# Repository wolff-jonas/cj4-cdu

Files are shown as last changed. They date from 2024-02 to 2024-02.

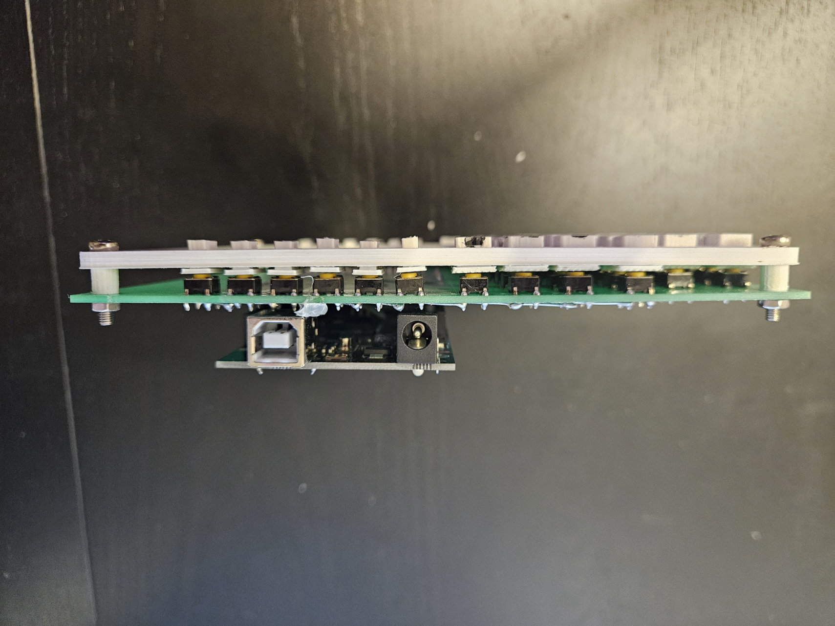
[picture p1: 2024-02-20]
images/side.jpg

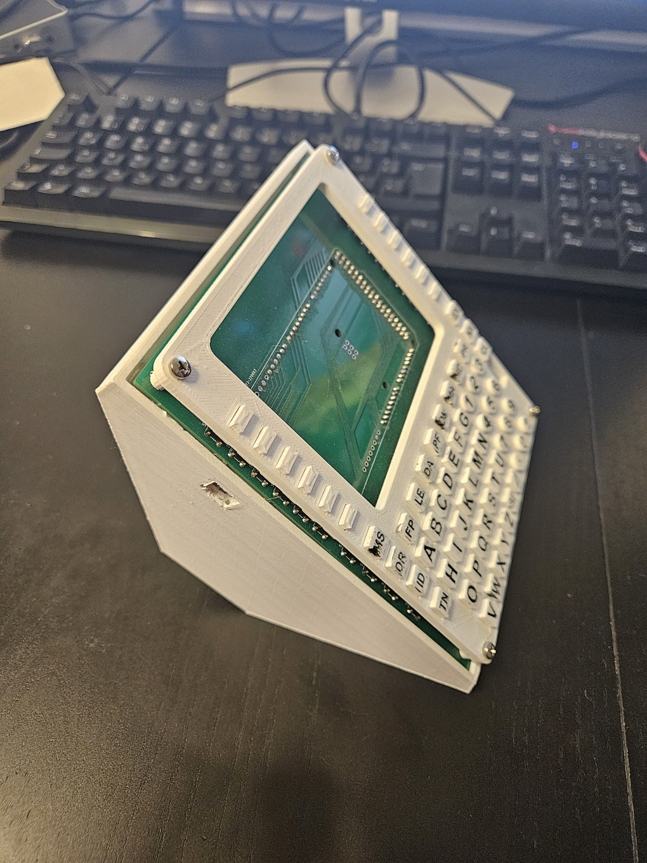
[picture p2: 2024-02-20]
images/side_stand.jpg

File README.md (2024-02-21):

# Overview

This is a physical button box in the rough shape and functionality of the CDU of the Citation CJ4.
It is primarily intended for use with Microsoft Flight Simulator 2020, but could be adapted to other simulators (or planes) as well.

For more indepth information head over to: https://jwolff.it/cj4-cdu/

## Hardware 

It's constructed with a 3D printed front plate, 3D printed keys, a custom PCB and an Arduino Mega.

The CAD for the front plate, and the 3 different kinds of keys are in CAD/ folder.
The is only one key for each type. For the whole keyboard you would have to copy and modify them with the labeling.

The schematics and design files for the PCB are in the kicad/ folder.

> [!CAUTION]
> If you plan on using the PCB: __triple check the footprints__ of the buttons!
>
> The buttons I ordered had different footprints. I had manually rework all the ground wires to make it work.
> I did __not__ update the PCB.

## Software

This uses [Mobiflight](https://www.mobiflight.com) for sending the correct key events to the sim.
Make sure you have the WASM module installed and downloaded the CJ4 Preset from HubHop.

The configs file mobiflight are in the mobiflight/ folder.

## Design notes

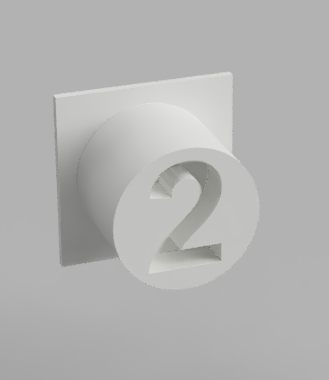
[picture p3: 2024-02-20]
images/button_round.png

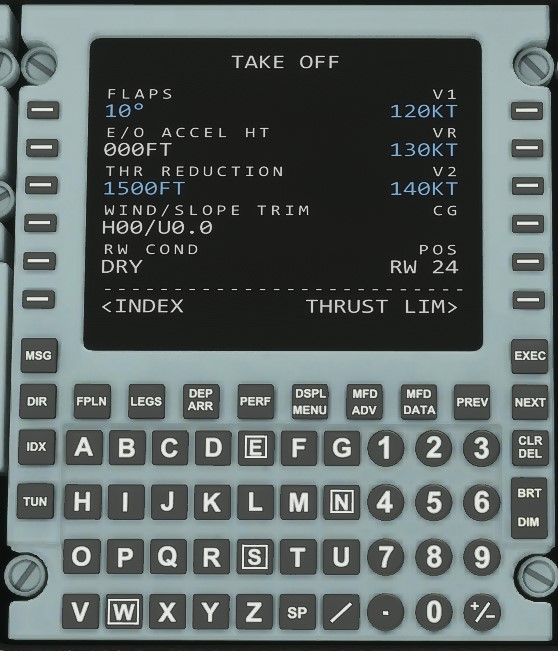
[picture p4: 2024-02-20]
images/screenshot.jpeg

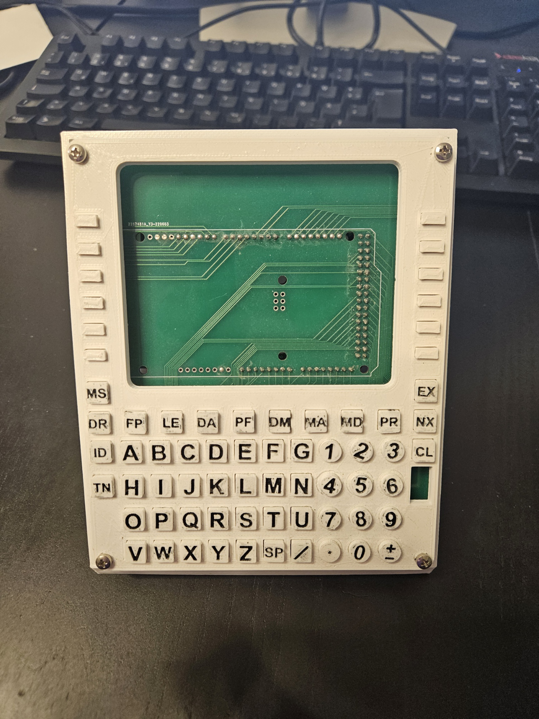
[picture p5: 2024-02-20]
images/front.jpg

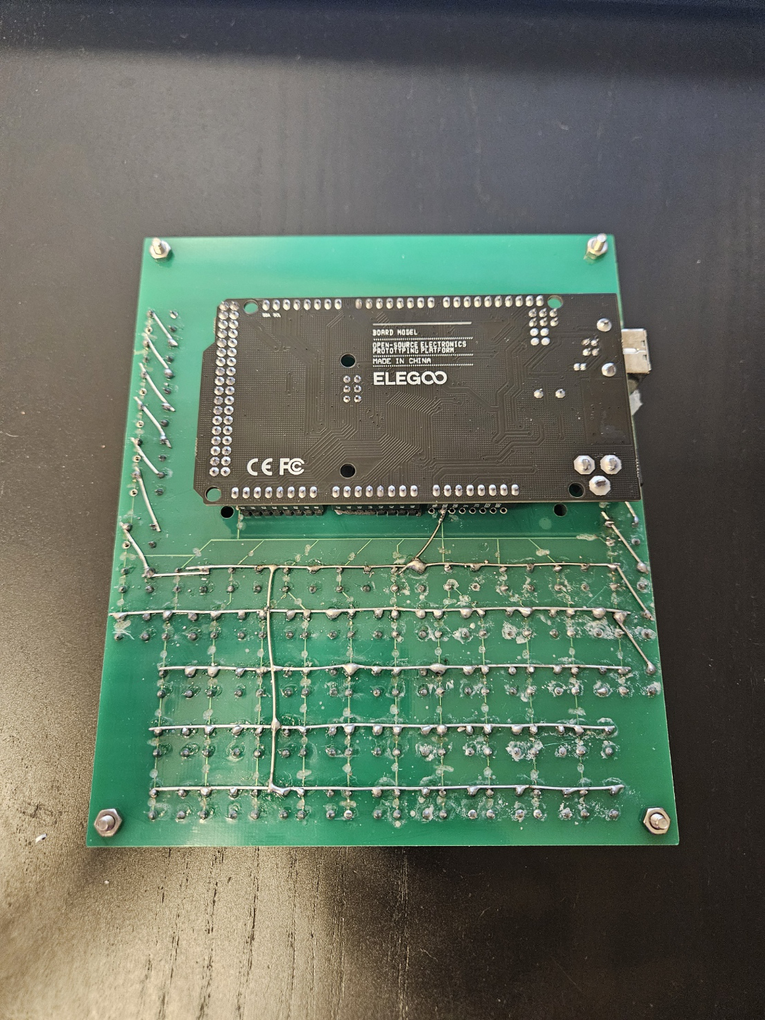
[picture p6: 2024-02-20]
images/back.jpg

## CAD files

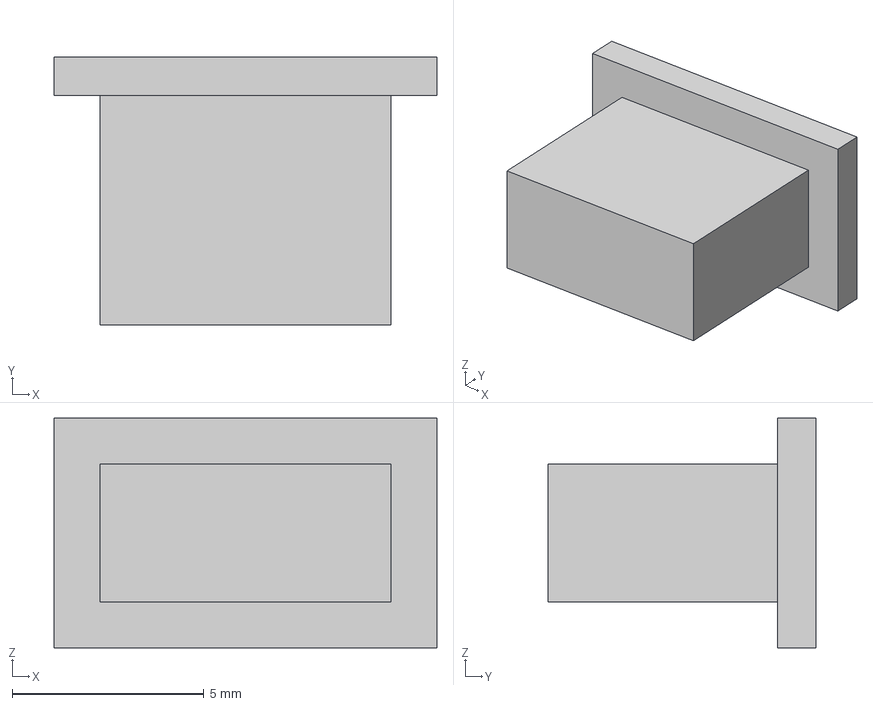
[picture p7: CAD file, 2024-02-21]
cad/key_lsk.step
10.0 x 7.00 x 6.00 mm

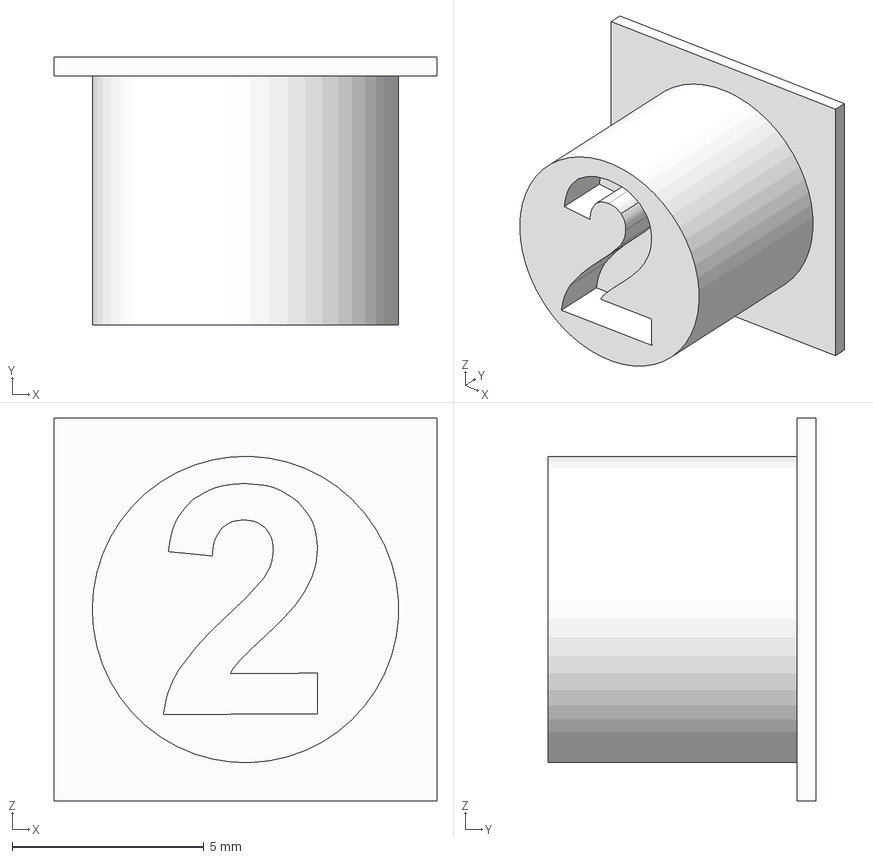
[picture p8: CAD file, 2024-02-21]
cad/key_round.step
10.0 x 7.00 x 10.0 mm

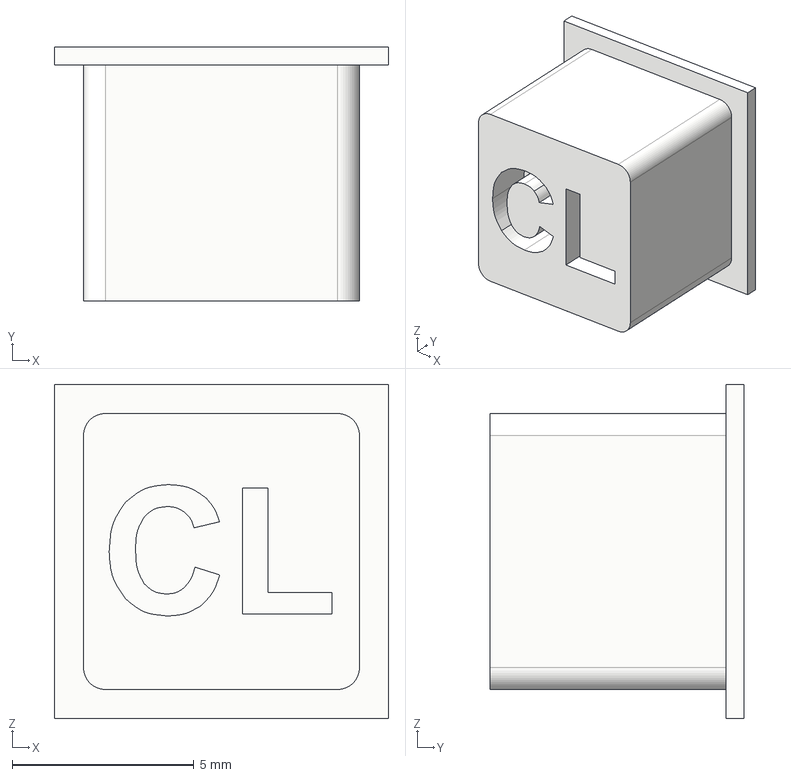
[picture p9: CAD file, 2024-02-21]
cad/key_square.step
9.20 x 7.00 x 9.20 mm

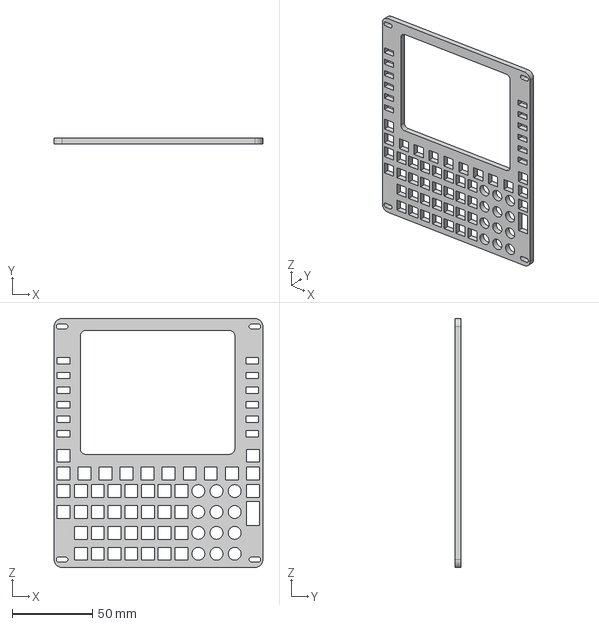
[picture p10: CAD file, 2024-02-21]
cad/frontpanel.step
130.0 x 4.00 x 155.0 mm

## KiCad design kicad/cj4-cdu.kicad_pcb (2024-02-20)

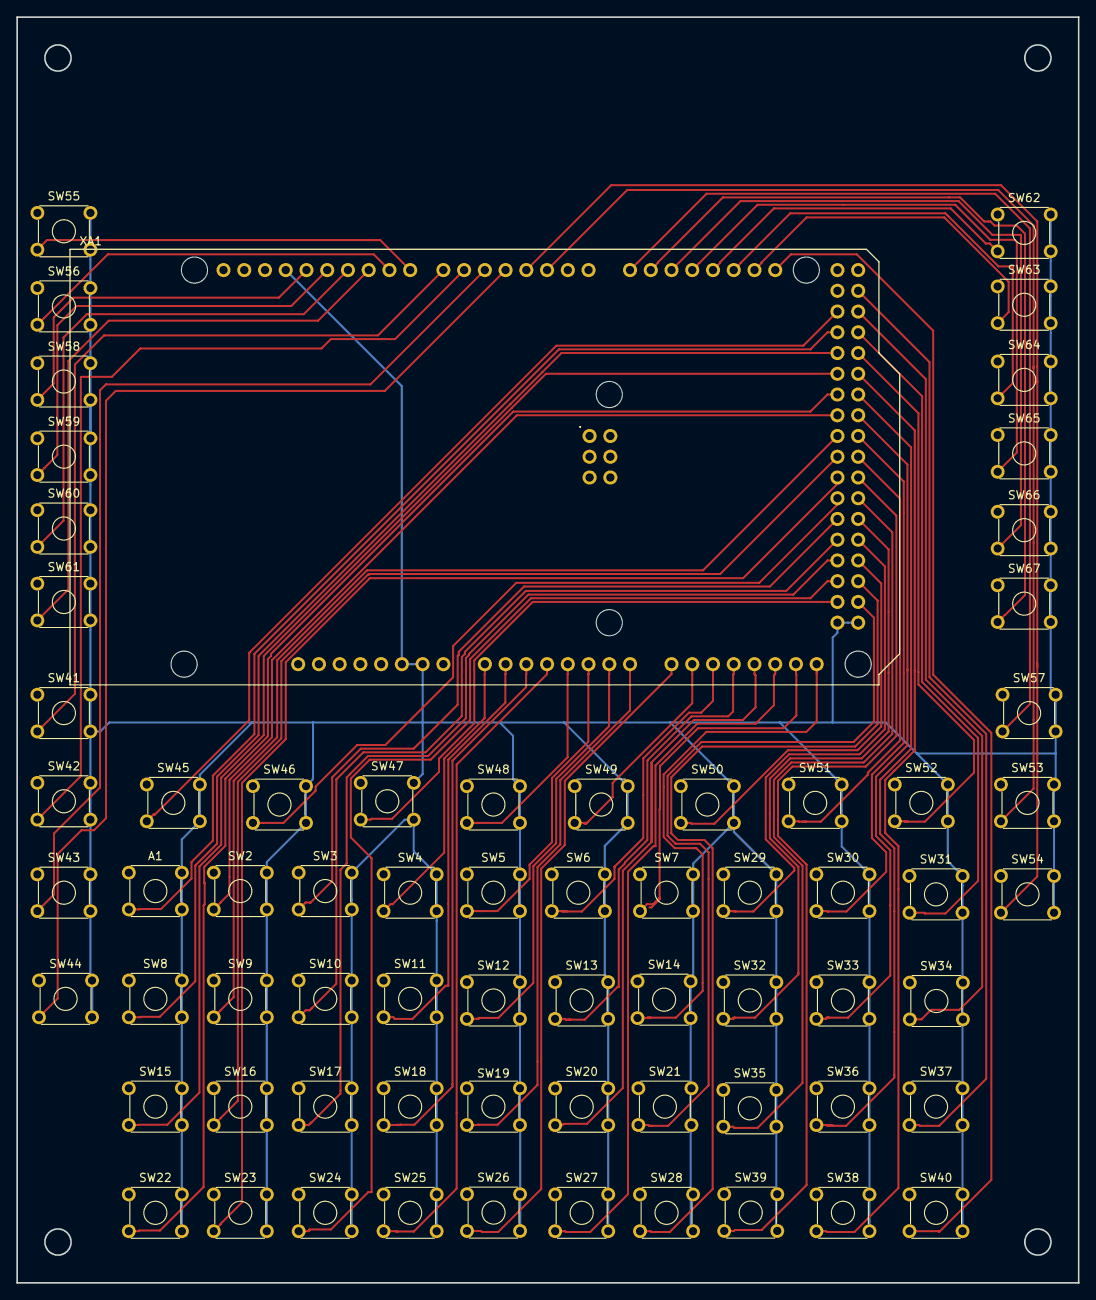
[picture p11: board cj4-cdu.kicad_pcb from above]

Board: 2 copper layers, 130.0 x 155.0 mm, 68 parts (0 on the bottom side), 68 nets.

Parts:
A1: A; SW_TH_Tactile_Omron_B3F-10xx
SW2: B; SW_TH_Tactile_Omron_B3F-10xx
SW3: C; SW_TH_Tactile_Omron_B3F-10xx
SW4: D; SW_TH_Tactile_Omron_B3F-10xx
SW5: E; SW_TH_Tactile_Omron_B3F-10xx
SW6: F; SW_TH_Tactile_Omron_B3F-10xx
SW7: G; SW_TH_Tactile_Omron_B3F-10xx
SW8: H; SW_TH_Tactile_Omron_B3F-10xx
SW9: I; SW_TH_Tactile_Omron_B3F-10xx
SW10: J; SW_TH_Tactile_Omron_B3F-10xx
SW11: K; SW_TH_Tactile_Omron_B3F-10xx
SW12: L; SW_TH_Tactile_Omron_B3F-10xx
SW13: M; SW_TH_Tactile_Omron_B3F-10xx
SW14: N; SW_TH_Tactile_Omron_B3F-10xx
SW15: Q; SW_TH_Tactile_Omron_B3F-10xx
SW16: P; SW_TH_Tactile_Omron_B3F-10xx
SW17, SW18, SW19, SW20, SW21, SW22, SW23, SW24, SW25, SW26, SW27, SW28, SW29, SW30, SW31, SW32, SW33, SW34, SW35, SW36, SW37, SW38, SW39, SW40, SW41, SW42, SW43, SW44, SW45, SW46, SW47, SW48, SW49, SW50, SW51, SW52, SW53, SW54, SW55, SW56, SW57, SW58, SW59, SW60, SW61, SW62, SW63, SW64, SW65, SW66, SW67: SW_DPST; SW_TH_Tactile_Omron_B3F-10xx
XA1: Arduino_Mega2560_Shield

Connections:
/0: SW38.3, XA1.D31
/1: SW29.3, XA1.D47
/2: SW30.3, XA1.D37
/3: SW31.3, XA1.D27
/4: SW32.3, XA1.D45
/5: SW33.3, XA1.D35
/6: SW34.3, XA1.D25
/7: SW35.3, XA1.D43
/8: SW36.3, XA1.D33
/9: SW37.3, XA1.D23
/A: A1.3, XA1.D26
/B: SW2.3, XA1.D34
/C: SW3.3, XA1.D44
/CLRDEL: SW54.3, XA1.D3
/D: SW4.3, XA1.A0
/DEPARR: SW47.3, XA1.D52
/DIR: SW42.3, XA1.D6
/DOT: SW39.3, XA1.D41
/DSPLMENU: SW49.3, XA1.A9
/E: SW5.3, XA1.A5
/EXEC: SW57.3, XA1.D14
/F: SW6.3, XA1.A10
/FPLN: SW45.3, XA1.D24
/G: SW7.3, XA1.A14
/H: SW8.3, XA1.D28
/I: SW9.3, XA1.D36
/IDX: SW43.3, XA1.D5
/J: SW10.3, XA1.D46
/K: SW11.3, XA1.A1
/L: SW12.3, XA1.A6
/LEGS: SW46.3, XA1.D42
/LSK_L1: SW55.3, XA1.D8
/LSK_L2: SW56.3, XA1.D9
/LSK_L3: SW58.3, XA1.D13
/LSK_L4: SW59.3, XA1.D12
/LSK_L5: SW60.3, XA1.D11
/LSK_L6: SW61.3, XA1.D10
/LSK_R1: SW62.3, XA1.D18
/LSK_R2: SW63.3, XA1.D20
/LSK_R3: SW64.3, XA1.D19
/LSK_R4: SW65.3, XA1.D17
/LSK_R5: SW66.3, XA1.D16
/LSK_R6: SW67.3, XA1.D15
/M: SW13.3, XA1.A11
/MFDADV: SW50.3, XA1.D49
/MFDDATA: SW51.3, XA1.D39
/MSG: SW41.3, XA1.D7
/N: SW14.3, XA1.A15
/NEXT: SW53.3, XA1.D2
/O: SW15.3, XA1.D30
/P: SW16.3, XA1.D38
/PERF: SW48.3, XA1.A4
/PLUSMINUS: SW40.3, XA1.D21
/PREV: SW52.3, XA1.D29
/Q: SW17.3, XA1.D48
/R: SW18.3, XA1.A2
/S: SW19.3, XA1.A7
/SLASH: SW28.3, XA1.D51
/SP: SW27.3, XA1.A13
/T: SW20.3, XA1.A12
/TUN: SW44.3, XA1.D4
/U: SW21.3, XA1.D53
/V: SW22.3, XA1.D32
/W: SW23.3, XA1.D40
/X: SW24.3, XA1.D50
/Y: SW25.3, XA1.A3
/Z: SW26.3, XA1.A8
GND: A1.2, A1.4, SW2.2, SW2.4, SW3.2, SW3.4, SW4.2, SW4.4, SW5.2, SW5.4, SW6.2, SW6.4, SW7.2, SW7.4, SW8.2, SW8.4, SW9.2, SW9.4, SW10.2, SW10.4, SW11.2, SW11.4, SW12.2, SW12.4, SW13.2, SW13.4, SW14.2, SW14.4, SW15.2, SW15.4, SW16.2, SW16.4, SW17.2, SW17.4, SW18.2, SW18.4, SW19.2, SW19.4, SW20.2, SW20.4, SW21.2, SW21.4, SW22.2, SW22.4, SW23.2, SW23.4, SW24.2, SW24.4, SW25.2, SW25.4, SW26.2, SW26.4, SW27.2, SW27.4, SW28.2, SW28.4, SW29.2, SW29.4, SW30.2, SW30.4, SW31.2, SW31.4, SW32.2, SW32.4, SW33.2, SW33.4, SW34.2, SW34.4, SW35.2, SW35.4, SW36.2, SW36.4, SW37.2, SW37.4, SW38.2, SW38.4, SW39.2, SW39.4, SW40.2, SW40.4, SW41.2, SW41.4, SW42.2, SW42.4, SW43.2, SW43.4, SW44.2, SW44.4, SW45.2, SW45.4, SW46.2, SW46.4, SW47.2, SW47.4, SW48.2, SW48.4, SW49.2, SW49.4, SW50.2, SW50.4, SW51.2, SW51.4, SW52.2, SW52.4, SW53.2, SW53.4, SW54.2, SW54.4, SW55.2, SW55.4, SW56.2, SW56.4, SW57.2, SW57.4, SW58.2, SW58.4, SW59.2, SW59.4, SW60.2, SW60.4, SW61.2, SW61.4, SW62.2, SW62.4, SW63.2, SW63.4, SW64.2, SW64.4, SW65.2, SW65.4, SW66.2, SW66.4, SW67.2, SW67.4, XA1.GND1, XA1.GND2, XA1.GND3, XA1.GND5, XA1.GND6

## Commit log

2024-02-20 CAD, KiCad, Mobiflight and Images
    [CJ4-CDU.step, cj4-cdu.kicad_pcb, cj4-cdu.sch]
2024-02-21 New CAD files and updated readme
    [CJ4-CDU.step, frontpanel.step, key_lsk.step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]
